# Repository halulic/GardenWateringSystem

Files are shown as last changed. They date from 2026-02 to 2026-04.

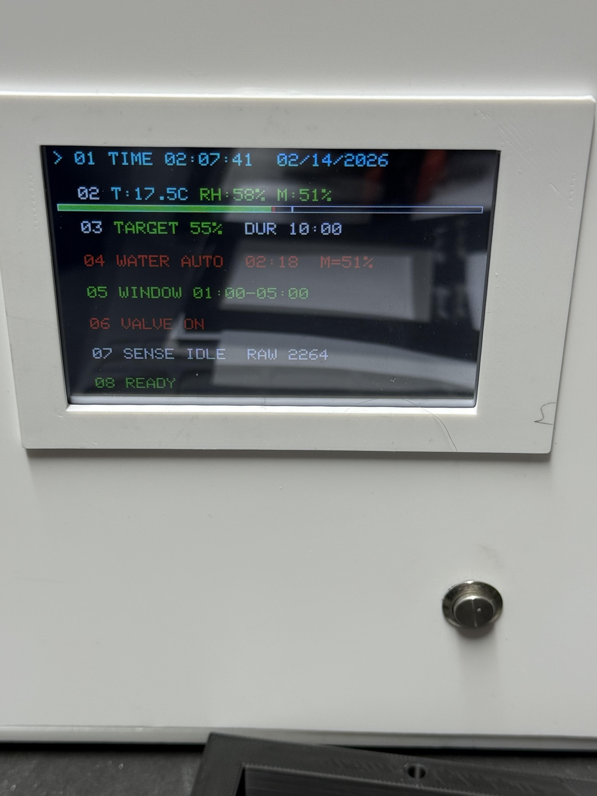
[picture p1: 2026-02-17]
Software/WSscaleALv4CN/GardenWateringSystem/Pictures/fp.jpg

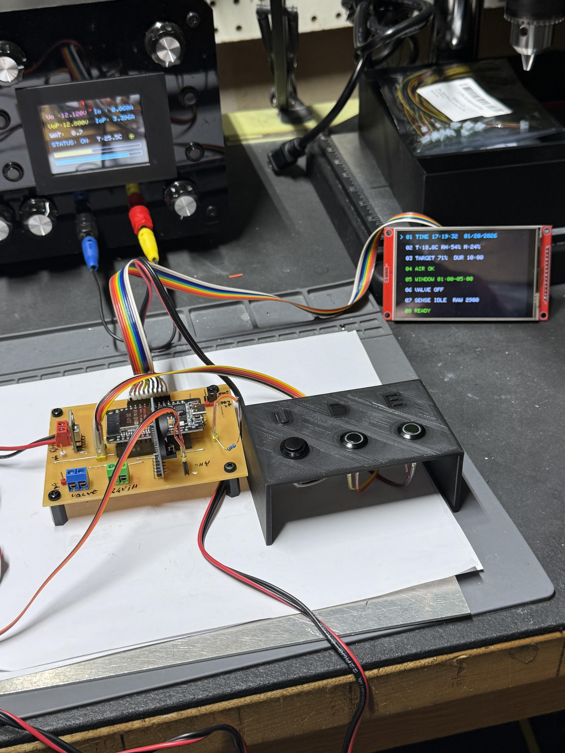
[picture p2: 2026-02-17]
Software/WSscaleALv4CN/GardenWateringSystem/Pictures/ftft.jpg

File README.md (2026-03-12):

Overview

This project is an automatic plant watering system based on ESP32.
It monitors soil moisture, temperature, and humidity and controls a water valve or pump to keep the soil moisture at a defined target level.

The system uses a TFT display for real-time monitoring and allows simple configuration of watering parameters.

⸻

Main Features
	•	Automatic watering based on soil moisture
	•	ESP32 microcontroller
	•	TFT display interface
	•	Real-time monitoring of:
	•	Soil moisture
	•	Temperature
	•	Humidity
	•	Adjustable target moisture level
	•	MOSFET-controlled water valve or pump
	•	Clear visual status indicators on the display

⸻

Hardware

Main components used:
	•	ESP32 development board
	•	Soil moisture sensor
	•	SHT41 temperature & humidity sensor
	•	DS3231 RTC
	•	4.0” TFT display (ILI9488)
	•	MOSFET driver (AO3400)
	•	Water valve or pump
	•	24V power supply (for valves)

⸻

Display Information

The TFT display shows:
	•	Soil moisture percentage
	•	Temperature
	•	Humidity
	•	Target moisture level
	•	Valve status
	•	System status indicators

⸻

Applications
	•	Indoor plant watering
	•	Greenhouse automation
	•	Garden irrigation control
	•	Experimental ESP32 automation projects

⸻

Future Improvements

Planned upgrades include:
	•	WiFi monitoring
	•	Data logging
	•	Mobile notifications
	•	Multi-zone watering control

⸻

License

Open-source project for educational and DIY use.

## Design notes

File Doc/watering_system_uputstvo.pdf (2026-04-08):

## WATERING SYSTEM – UPUTSTVO

Ovaj dokument opisuje rad sistema, navigaciju kroz redove na TFT-u, podešavanja i rad AI (AL) u pozadini.

## ROW 01 – TIME (VREME I DATUM)

Ulaz: kratki ENTER kada je selektovan red 01.
UP/DOWN menjaju vrednosti.
ENTER prelazi na slede■e polje (sat → minut → mesec → dan → godina). Na kraju ENTER potvr■uje i izlazi.

## ROW 02 – MOIST / WET / DRY

Ulaz u edit: držati ENTER 5 sekundi.
Blink ozna■ava aktivno polje.
UP/DOWN menjaju RAW vrednosti (korak 10). ENTER kratko prebacuje izme■u WET i DRY. Držati ENTER ~2 sekunde za save + izlaz. Ove vrednosti su zaklju■ane i AI ih ne menja.

## ROW 03 – TARGET / DUR

Ulaz: kratki ENTER.
TARGET – željena vlažnost (30–85%).
DUR – trajanje zalivanja (3–10 min).
UP/DOWN menjaju vrednosti.
ENTER prelazi izme■u TARGET i DUR, zatim izlaz.

## ROW 04 – SCL (SCALE)

Ulaz: ENTER na red 04.
SCL = skaliranje vlage (60–100%).
UP/DOWN menjaju vrednost po 1%.
ENTER potvr■uje i odmah vrši novo merenje. SCL uti■e i na prikaz i na logiku zalivanja.

## CAL STATUS

CAL+ = kalibracija dobra.
CAL~ = u toku u■enja.
CAL! = problem (sonda ili opseg).

## ROW 07 – SENSE

Prikazuje stanje senzora.
RAW vrednost = direktno o■itanje. OPEN = nema kontakta sa zemljom. SHORT = kratak spoj.

## AI (AL) RAD U POZADINI

AI prati istoriju vlage, temperaturu i ponašanje tla.
Ra■una brzinu sušenja i predvi■a kada ■e pasti ispod TARGET. Detektuje anomalije (skokovi, loš kontakt, bez oporavka).
Ne menja korisni■ke WET/DRY vrednosti.

## KADA O■EKIVATI TA■NE REZULTATE

Osnovna stabilizacija: odmah nakon prvih nekoliko merenja. AI preciznost: nakon 1–3 dana rada.
Optimalno: 3–5 dana kontinuiranog rada.

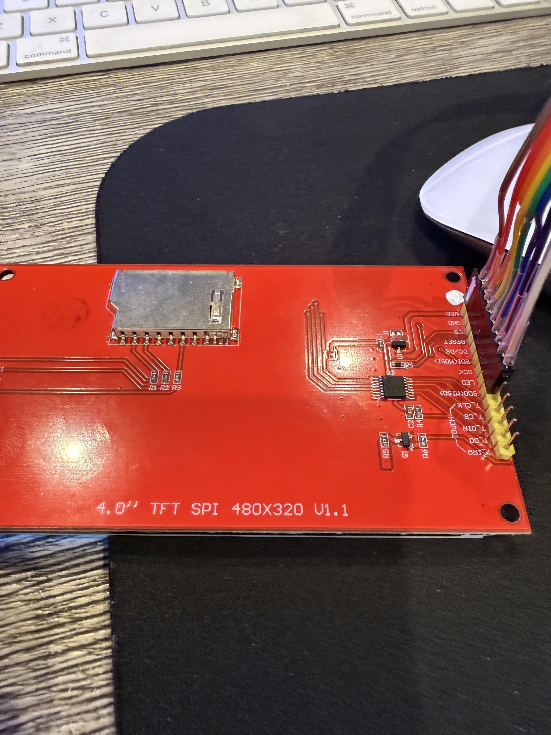
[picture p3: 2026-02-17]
Software/WSscaleALv4CN/GardenWateringSystem/Pictures/tft4in.jpg

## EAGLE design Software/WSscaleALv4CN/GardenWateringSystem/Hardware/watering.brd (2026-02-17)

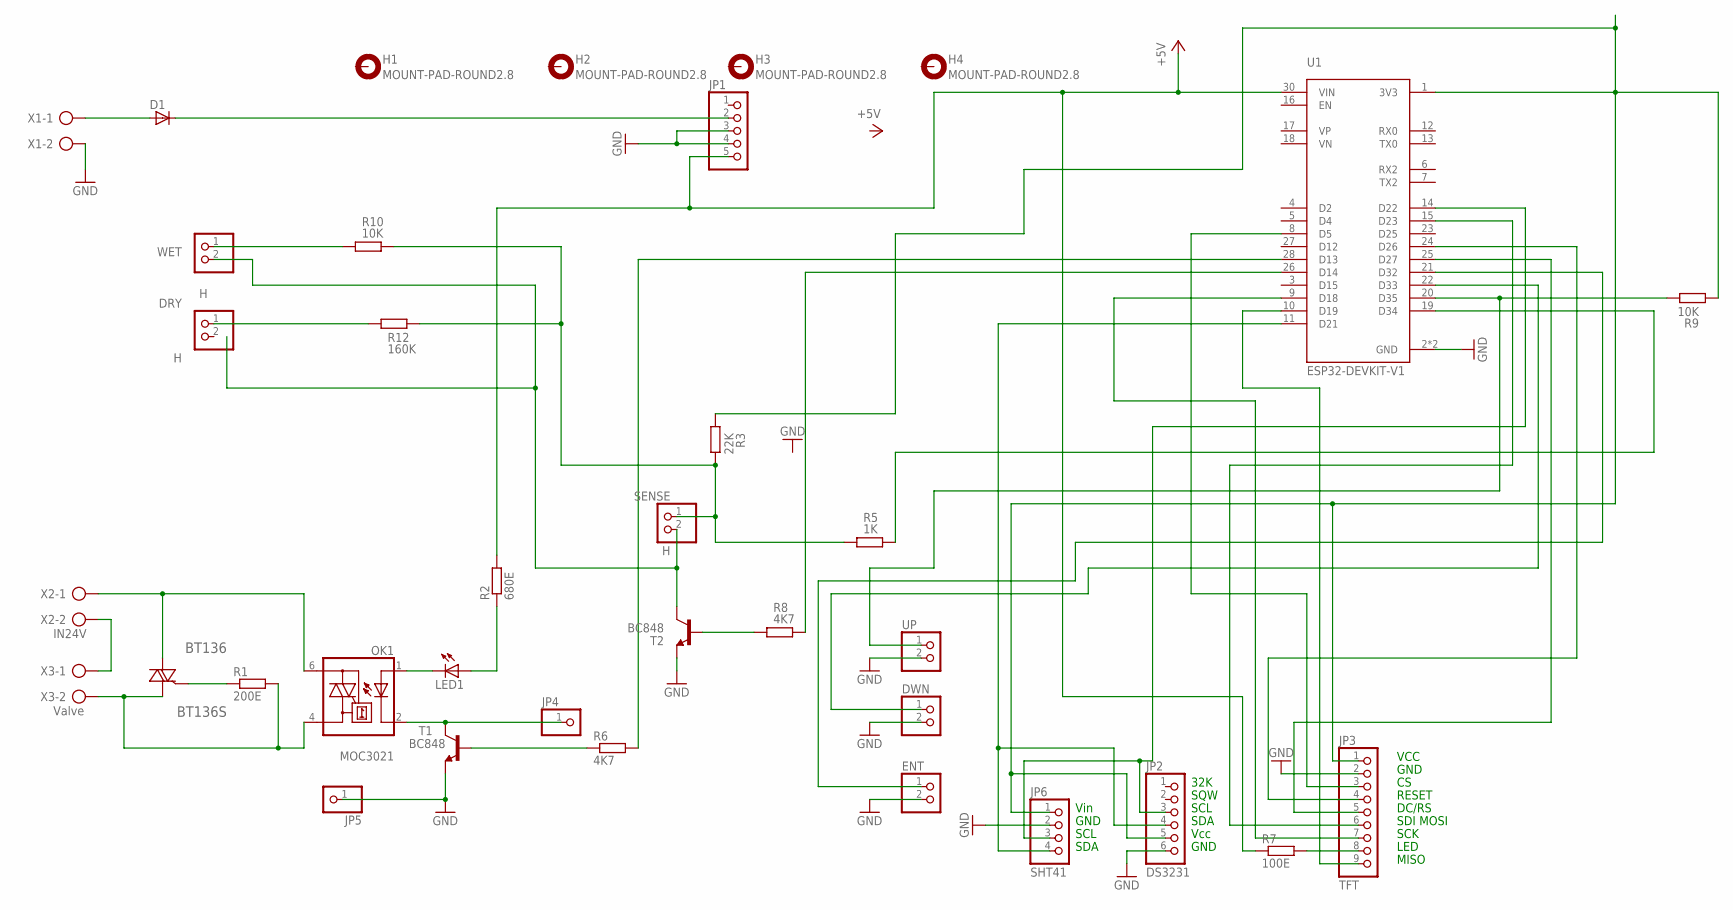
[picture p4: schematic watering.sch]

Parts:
BT136: BT136S; DPAK228P987X240-3N
D1: D-SOD-80; SOD80
DRY: H; 1X02
DWN: PINHD-1X2; 1X02
ENT: PINHD-1X2; 1X02
H1, H2, H3, H4: MOUNT-PAD-ROUND2.8; 2,8-PAD
JP1: PINHD-1X5; 1X05
JP2: DS3231; 1X06
JP3: TFT; 1X09
JP4, JP5: PINHD-1X1; 1X01
JP6: SHT41; 1X04
LED1: LEDCHIPLED_0805; CHIPLED_0805
OK1: MOC3021; DIL6-SMD
R1: 200E; R0603
R2: 680E; R0603
R3: 22K; R0603
R5: 1K; R0603
R6, R8: 4K7; R0603
R7: 100E; R0603
R9, R10: 10K; R0603
R12: 160K; R0603
SENSE: H; 1X02
T1, T2: BC848; SOT23
U1: ESP32-DEVKIT-V1; MODULE_ESP32_DEVKIT_V1
UP: PINHD-1X2; 1X02
WET: H; 1X02
X1: AK300/2
X2: IN24V; AK300/2
X3: Valve; AK300/2

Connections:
+5V: JP1.5, R2.2, R7.1, U1.30 (VIN)
GND: DWN.2, ENT.2, JP1.3, JP1.4, JP2.6, JP3.2, JP5.1, JP6.2, T1.2 (E), T2.2 (E), U1.2 (GND), U1.29 (GND), UP.2, X1.2
unnamed: X2.2, X3.1
unnamed: BT136.1 (A1), OK1.4 (A1), R1.2, X3.2
unnamed: BT136.3 (A2), OK1.6 (A2), X2.1
unnamed: JP2.5, JP3.1, JP6.1, R3.1, R9.1, U1.1 (3V3)
unnamed: BT136.2 (G), R1.1
unnamed: LED1.A, R2.1
unnamed: JP4.1, OK1.2 (C), T1.3 (C)
unnamed: LED1.C, OK1.1 (A)
unnamed: D1.2 (A), X1.1
unnamed: D1.1 (C), JP1.2
unnamed: R3.2, R5.1, R10.2, R12.2, SENSE.1
unnamed: DRY.1, R12.1
unnamed: R6.1, T1.1 (B)
unnamed: JP3.8, R7.2
unnamed: SENSE.2, T2.3 (C), WET.2
unnamed: R8.1, T2.1 (B)
unnamed: R10.1, WET.1
unnamed: JP2.3, JP6.3, U1.14 (D22)
unnamed: JP2.4, JP6.4, U1.11 (D21)
unnamed: JP3.7, U1.9 (D18)
unnamed: R8.2, U1.26 (D14)
unnamed: JP3.6, U1.15 (D23)
unnamed: R9.2, U1.20 (D35), UP.1
unnamed: JP3.3, U1.8 (D5)
unnamed: JP3.5, U1.25 (D27)
unnamed: JP3.4, U1.24 (D26)
unnamed: JP3.9, U1.10 (D19)
unnamed: DWN.1, U1.22 (D33)
unnamed: ENT.1, U1.21 (D32)
unnamed: R6.2, U1.28 (D13)
unnamed: R5.2, U1.19 (D34)

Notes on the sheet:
VCC
GND
RESET
DC/RS
SDI MOSI
SCK
LED
MISO
32K
SQW
SCL
SDA
Vcc
Vin

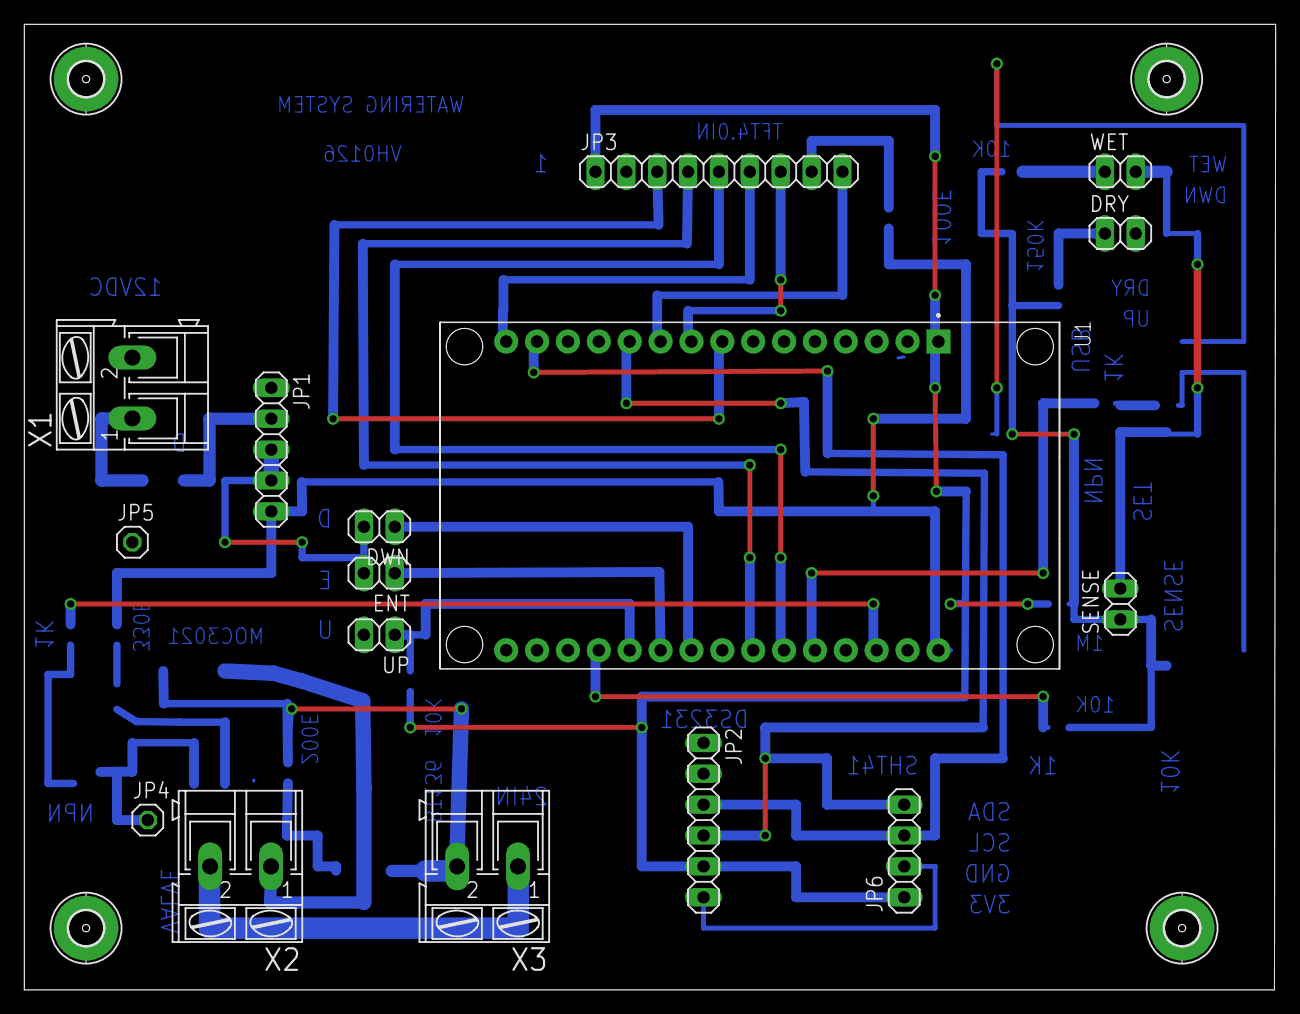
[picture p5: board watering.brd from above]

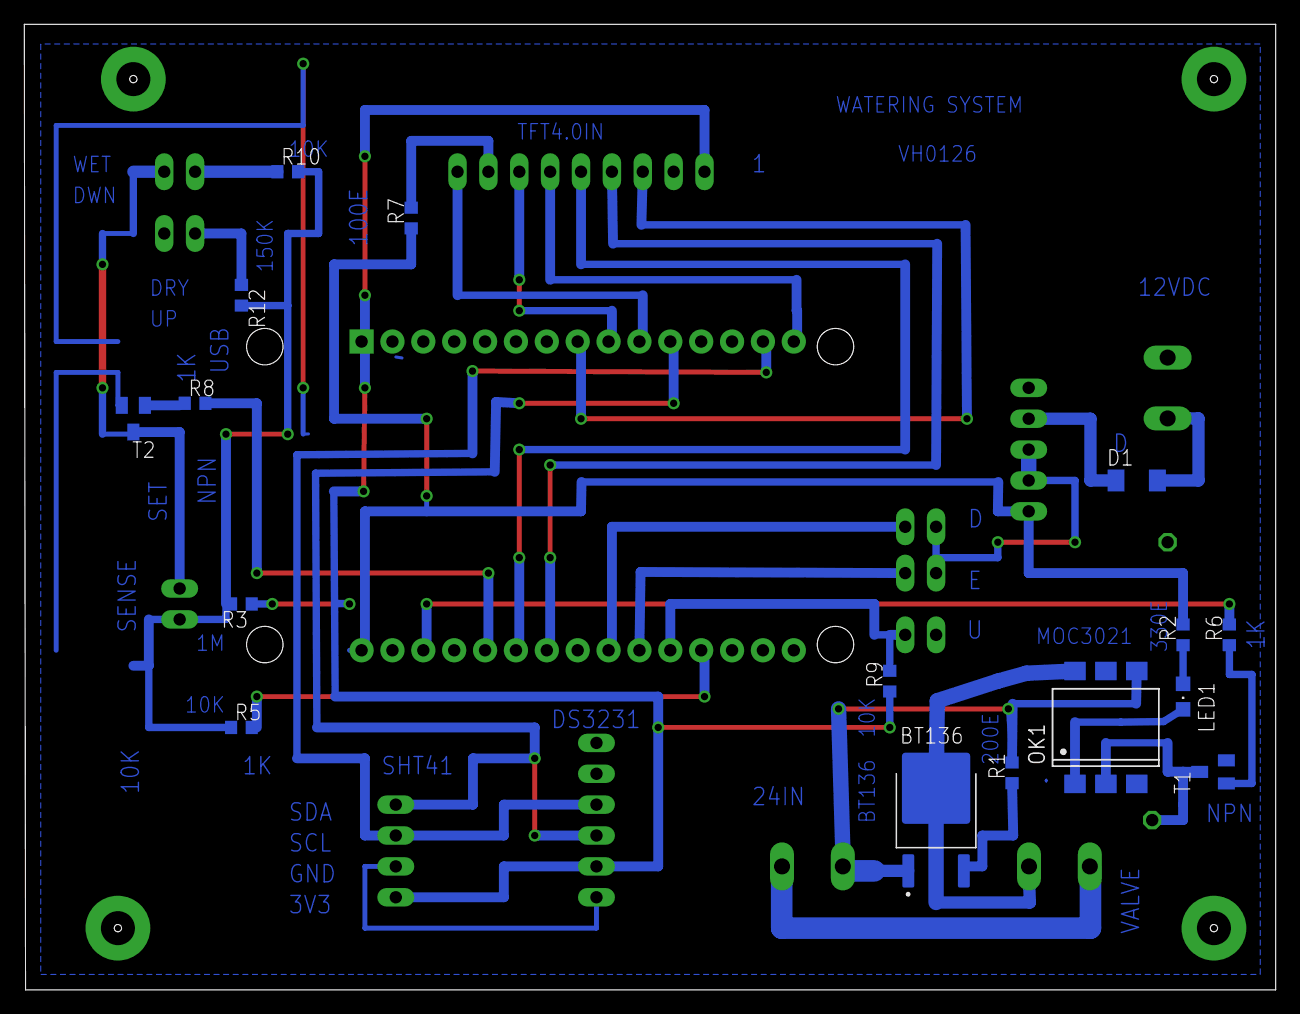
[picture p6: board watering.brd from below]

Board: 2 copper layers, 103.0 x 79.4 mm, 36 parts (16 on the bottom side), 33 nets.

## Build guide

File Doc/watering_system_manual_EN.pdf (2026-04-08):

## WATERING SYSTEM – USER MANUAL

This document explains system operation, TFT rows navigation, settings, and background AI behavior.

## ROW 01 – TIME & DATE

Enter: short ENTER press when row 01 is selected.
UP/DOWN adjust values.
ENTER moves through fields (hour → minute → month → day → year). Final ENTER saves and exits.

## ROW 02 – MOIST / WET / DRY

Enter edit: hold ENTER for 5 seconds.
Blink indicates active field.
UP/DOWN adjust RAW values (step 10).
Short ENTER switches between WET and DRY. Hold ENTER ~2 seconds to save and exit.
These values are user-locked (AI will not modify them).

## ROW 03 – TARGET / DURATION

Enter: short ENTER.
TARGET – desired moisture (30–85%).
DURATION – watering time (3–10 minutes).
UP/DOWN adjust values.
ENTER switches between TARGET and DURATION, then exits.

## ROW 04 – SCALE (SCL)

Enter: ENTER on row 04.
SCL = moisture scaling (60–100%).
UP/DOWN adjust by 1%.
ENTER saves and triggers immediate measurement. Affects both display and watering logic.

## CAL STATUS

CAL+ = calibration OK.
CAL~ = learning in progress.
CAL! = issue detected (sensor or range).

## ROW 07 – SENSOR (SENSE)

Displays sensor status.
RAW value = direct reading.
OPEN = no soil contact.
SHORT = short circuit.

## BACKGROUND AI (AL)

AI monitors moisture history, temperature, and soil behavior.
Calculates drying rate and predicts when moisture drops below TARGET. Detects anomalies (jumps, stuck values, no recovery).
Does NOT modify user WET/DRY settings.

## WHEN TO EXPECT ACCURATE RESULTS

Basic stabilization: after initial measurements.
AI accuracy: after 1–3 days of operation.
Optimal performance: after 3–5 days continuous use.

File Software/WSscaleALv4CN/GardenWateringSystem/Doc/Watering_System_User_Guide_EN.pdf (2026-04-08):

## WATERING SYSTEM – USER GUIDE

This document is a complete user guide for the Watering System. It explains how the system operates, how values are measured and displayed, how parameters are configured, and how the TFT screen information should be interpreted.

VH
01/21/2026 – 03:10 AM (WVC)

### 1. What is the Watering System

The Watering System is an automatic irrigation controller that independently decides when and how long to water based on soil moisture, air temperature, and time.

### Hardware Platform

1 ESP32 Dev Module – 30■pin version (main system controller).
2 4.0" TFT display – graphical presentation of all system information.
3 SHT41 – digital air temperature and humidity sensor.
4 DS3231 – real■time clock (RTC) module for accurate time and date.
5 Soil moisture sensor – resistive type, powered only during measurements. 6 24 VAC irrigation valve – watering control output.

### 2. How the system makes decisions

1 The system operates only within the allowed watering window (01:00–05:00). 2 Air temperature is checked first.
3 If the temperature is ≤ 12 °C, watering is blocked.
4 Soil moisture is then measured.
5 If soil moisture is ≥ TARGET, watering is skipped.
6 If soil moisture is below TARGET, the valve is activated for the set duration (DUR).

### 3. When and how soil moisture is measured

The system does not measure soil moisture continuously. Measurements are performed only at defined moments to ensure reliability and to protect the soil probe from degradation.
1 Before watering (within the 01:00–05:00 window).
2 Immediately after watering has finished.
3 Later during the day at 06:00, 12:00, and 18:00.

### 4. Soil moisture before, during, and after watering

Before watering, the system measures soil moisture and decides whether watering is required. During watering, no new measurement is performed. The last valid moisture value remains displayed while the VALVE status shows ON.
After watering, soil moisture is measured again and the new value is stored as the reference for subsequent decisions.

### 5. Why soil moisture does not increase immediately

After watering, water initially remains near the soil surface. It takes time for moisture to reach the depth where the probe is located. For this reason, an increase in soil moisture is often visible only at the next measurement cycle.

### 6. TFT display – meaning of the information

01 TIME – current time and date.
02 T / RH / M – air temperature, air humidity, and soil moisture. 03 TARGET / DUR – target soil moisture and watering duration. 04 AIR – air status (blocked if too cold).
05 WINDOW – allowed watering time window.
06 VALVE – irrigation valve status.
07 SENSE – measurement status and raw ADC value. 08 READY – system is idle and ready.

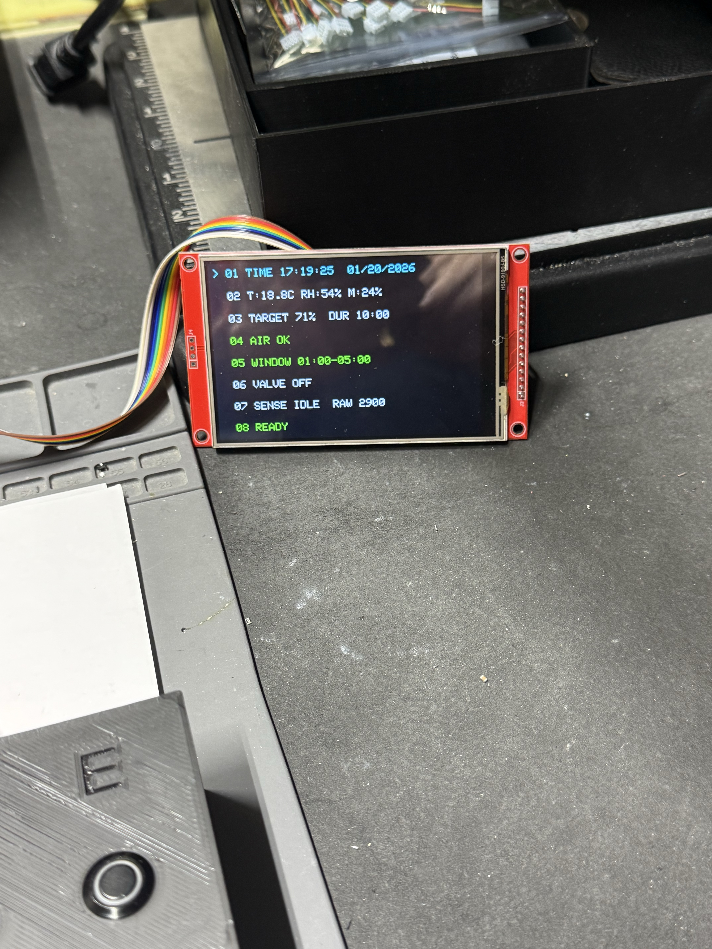
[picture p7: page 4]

### 7. Buttons: UP / DOWN / ENTER

UP – increases the selected value (TARGET or DUR). DOWN – decreases the selected value.
ENTER – confirms a selection or enters a setting mode.
ENTER held during power■up – enters CAL MODE.

### 8. CAL MODE – soil moisture calibration

CAL MODE is used to calibrate the soil moisture sensor. It is entered by holding the ENTER button while powering on the device. CAL MODE is exited by turning the power off and on again.

### 9. WET / DRY calibration

Calibration uses fixed resistors: DRY = 150 kΩ and WET = 10 kΩ. The resistors are connected between SENSE and GND through the NPN transistor collector, exactly as in normal system operation. The calibrated values are stored in memory.

### 10. Typical operating scenarios

1 If the temperature is too low, watering will not occur.
2 If soil moisture is above TARGET, watering is skipped.
3 When READY is displayed, the system is waiting for the next scheduled check.

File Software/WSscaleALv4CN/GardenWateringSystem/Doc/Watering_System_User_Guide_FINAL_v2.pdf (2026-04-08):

## WATERING SYSTEM – USER GUIDE

Ovo je kompletno uputstvo za rad Watering System-a. Sistem je baziran na ESP32 mikrokontroleru (30-pinski modul), koristi 4.0" TFT ekran za prikaz i SHT41 senzor za mjerenje temperature i vlažnosti zraka.

VH
01/21/2026 – 02:53 AM (WVC)

### 1. Hardverska osnova sistema

1 ESP32 Dev Module – 30 pinski modul (glavni kontroler sistema). 2 TFT ekran 4.0" – grafi■ki prikaz svih informacija i statusa sistema.
3 SHT41 – digitalni senzor temperature i vlažnosti zraka.
4 DS3231 – RTC modul za ta■no vrijeme i datum.
5 Senzor vlage tla – otpornog tipa, sa aktivacijom samo tokom mjerenja.
6 24 VAC ventil – upravljanje zalijevanjem.

### 2. Šta je Watering System

Watering System je automatski sistem za zalijevanje koji samostalno odlu■uje kada i koliko zalijevati, na osnovu vlage tla, temperature zraka i vremena.

### 3. Kako sistem razmišlja

1 Sistem radi samo u dozvoljenim vremenskim terminima (01–05).
2 Prvo provjerava temperaturu zraka.
3 Ako je temperatura ≤ 12 °C → zalijevanje je blokirano.
4 Zatim mjeri vlagu tla.
5 Ako je vlaga ≥ TARGET → zalijevanje se preska■e.
6 Ako je vlaga < TARGET → ventil se uklju■uje na DUR minuta.

### 4. Kada i kako sistem mjeri vlagu tla

Sistem ne mjeri vlagu stalno. Mjerenje se vrši samo u ta■no odre■enim trenucima radi pouzdanosti i zaštite sonde.
1 Prije zalijevanja (01–05).
2 Odmah nakon završenog zalijevanja.
3 Kasnije tokom dana u 06:00, 12:00 i 18:00.

### 5. Vlažnost tla prije, tokom i nakon zalijevanja

Prije zalijevanja sistem mjeri vlagu tla i donosi odluku da li je zalijevanje potrebno.
Tokom zalijevanja ne vrši se novo mjerenje. Na ekranu ostaje posljednja izmjerena vrijednost, dok red VALVE pokazuje stanje ON.
Nakon zalijevanja sistem ponovo mjeri vlagu tla i ta vrijednost se koristi kao nova referenca.

### 6. Zašto se vlaga ne pove■a odmah nakon zalijevanja

Voda nakon zalijevanja ostaje u gornjem sloju tla i potrebno je vrijeme da dopre do dubine na kojoj se nalazi sonda. Zbog toga se porast vlage ■esto vidi tek na sljede■em mjerenju.

### 7. TFT ekran – zna■enje prikaza

01 TIME – trenutno vrijeme i datum.
02 T / RH / M – temperatura zraka, vlažnost zraka i vlaga tla. 03 TARGET / DUR – ciljana vlaga i trajanje zalijevanja.
04 AIR – status zraka (blokada ako je hladno).
05 WINDOW – dozvoljeni vremenski prozor.
06 VALVE – stanje ventila.
07 SENSE – stanje mjerenja i RAW vrijednost. 08 READY – sistem spreman za rad.


### 8. Tasteri UP / DOWN / ENTER

UP – pove■ava vrijednost (TARGET, DUR). DOWN – smanjuje vrijednost.
ENTER – potvrda ili ulaz u podešavanje.
ENTER držan pri paljenju – ulazak u CAL MODE.

### 9. CAL MODE – kalibracija vlage

CAL MODE služi za kalibraciju senzora vlage tla. Ulazi se držanjem ENTER tastera tokom uklju■enja ure■aja. Izlazak iz CAL MODE je isklju■ivanje i ponovno uklju■ivanje napajanja.

### 10. WET / DRY kalibracija

Za kalibraciju se koriste otpornici: DRY = 150 kΩ i WET = 10 kΩ. Otpornici se spajaju izme■u SENSE i GND preko kolektora NPN tranzistora, isto kao u normalnom radu sistema. Vrijednosti se pamte u memoriji.

### 11. Tipi■ni scenariji

1 Ako je hladno → sistem ne■e zalijevati.
2 Ako je vlaga iznad TARGET → zalijevanje se preska■e. 3 Ako piše READY → sistem ■eka sljede■i termin.

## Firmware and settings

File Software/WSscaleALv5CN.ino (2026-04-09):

#include <Wire.h>
#include <RTClib.h>
#include <Adafruit_SHT4x.h>
#include <Arduino_GFX_Library.h>
#include <Preferences.h>
#include <math.h>

#define TFT_CS   5
#define TFT_DC   27
#define TFT_RST  26
#define TFT_SCK  18
#define TFT_MOSI 23
#define TFT_MISO -1

#define I2C_SDA  21
#define I2C_SCL  22

#define PIN_UP      35
#define PIN_DOWN    33
#define PIN_ENTER   32

#define PIN_SENSE_EN   14
#define PIN_SENSE_ADC  34
#define PIN_VALVE      13

Arduino_DataBus *bus = new Arduino_HWSPI(TFT_DC, TFT_CS, TFT_SCK, TFT_MOSI, TFT_MISO);
Arduino_GFX *gfx = new Arduino_ILI9488_18bit(bus, TFT_RST, 1, false);

uint16_t C_BLACK, C_WHITE, C_GREEN, C_YELLOW, C_RED, C_CYAN;
uint16_t C_SPRING, C_SUMMER, C_AMBER;

RTC_DS3231 rtc;
Adafruit_SHT4x sht4;
Preferences prefs;

static const int ROWS = 8;
static const int ROW_H = 40;
static const int LEFT = 8;

int TARGET = 50;
int DUR_MIN = 5;
int SCALE_PCT = 75;

static const int WINDOW_START_H = 1;
static const int WINDOW_END_H   = 5;

static const int DAILY_READ_H1 = 6;
static const int DAILY_READ_H2 = 12;
static const int DAILY_READ_H3 = 18;

static const int CAL_STEP = 10;
static const int SCALE_MIN = 60;
static const int SCALE_MAX = 100;
static const int TARGET_MIN = 30;
static const int TARGET_MAX = 85;

static const uint32_t CAL_ENTER_HOLD_MS = 5000;
static const uint32_t CAL_SAVE_EXIT_MS  = 2000;
static const uint32_t BLINK_MS = 350;

#define SOIL_RAW_SHORT_MAX   60
#define SOIL_RAW_OPEN_MIN    3850

static const int RAW_WET_INIT = 700;
static const int RAW_DRY_INIT = 2800;

int RAW_DRY = RAW_DRY_INIT;
int RAW_WET = RAW_WET_INIT;

int calDry = RAW_DRY_INIT;
int calWet = RAW_WET_INIT;

enum CalBgState {
  CAL_BG_LEARN = 0,
  CAL_BG_OK    = 1,
  CAL_BG_WARN  = 2
};

uint8_t calBgState = CAL_BG_OK;

float airT = NAN;
float airRH = NAN;

int moistRaw = 0;
int moistPct = 0;
int moistPctBaseFiltered = 0;

bool senseIdle = true;
bool tempBlock = false;

bool watering = false;
bool wateringManual = false;
uint32_t wateringEndMs = 0;

String lastLine[ROWS];
uint16_t lastFg[ROWS];

uint32_t lastAutoKey = 0;
uint32_t lastDailyKey = 0;

bool calEnterHoldFired = false;
bool calSaveHoldFired = false;
bool calBlinkOn = true;
uint32_t calBlinkMs = 0;
bool calWaitReleaseAfterEnter = false;

int  lastBarPct = -1;
int  lastBarTgt = -1;
bool lastBarHl  = false;

static const int SOIL_READ_SAMPLES = 24;
static const int SOIL_READ_DELAY_MS = 2;
static const int SOIL_RAW_DEADBAND = 18;
static const int SOIL_RAW_SNAP_BAND = 10;

static const float SOIL_TEMP_REF_C = 20.0f;
static const float SOIL_TEMP_RAW_PER_C = 6.0f;

static const int AI_HISTORY_MAX = 32;

static const int AI_JUMP_RAW_THRESHOLD = 450;
static const int AI_STUCK_RAW_WINDOW = 12;
static const int AI_STUCK_RAW_DELTA = 4;
static const int AI_RECOVERY_MIN_DELTA = 40;
static const uint32_t AI_RECOVERY_WINDOW_MS = 45UL * 60UL * 1000UL;

static const uint16_t SOIL_STARTUP_SETTLE_MS = 220;
static const uint16_t SOIL_NORMAL_SETTLE_MS  = 150;
static const uint8_t  SOIL_STARTUP_INTERNAL_READS = 3;
static const uint8_t  SOIL_NORMAL_INTERNAL_READS  = 3;
static const int      SOIL_STARTUP_STABLE_BAND = 35;
static const int      SOIL_NORMAL_STABLE_BAND  = 30;
static const uint8_t  SOIL_MAX_RETRIES = 2;

struct AiPoint {
  uint32_t epoch;
  int raw;
  int rawTempComp;
  int pct;
  float tC;
  float rh;
  bool wateringState;
  bool valid;
};

AiPoint aiHist[AI_HISTORY_MAX];
int aiHistCount = 0;
int aiHistHead = 0;

int moistRawFiltered = 0;
int moistPctFiltered = 0;
bool moistFilterPrimed = false;

float aiDryRatePctPerHour = 0.0f;
float aiPredHoursToTarget = -1.0f;
float aiConfidence = 0.0f;

bool aiAnomalyJump = false;
bool aiAnomalyStuck = false;
bool aiAnomalyNoRecovery = false;
bool aiSensorHealthBad = false;

bool aiSoilVeryWet = false;
bool aiSoilWet = false;
bool aiSoilOk = false;
bool aiSoilDry = false;
bool aiSoilCritical = false;

bool aiPrevWatering = false;
uint32_t aiLastWaterStopMs = 0;
int aiRawAtWaterStop = 0;

struct Button {
  int pin;
  bool activeLow = true;
  bool stable = false;
  bool raw = false;
  uint32_t lastChangeMs = 0;
  bool shortPress = false;
  bool longPress = false;
  bool longFired = false;
  uint32_t pressStartMs = 0;
  uint16_t debounceMs = 25;
  uint16_t longMs = 650;

  void begin(int p){
    pin = p;
    if(pin >= 34) pinMode(pin, INPUT);
    else pinMode(pin, INPUT_PULLUP);
    bool r = readRawPressed();
    stable = r;
    raw = r;
    lastChangeMs = millis();
  }

  bool readRawPressed(){
    int v = digitalRead(pin);
    return activeLow ? (v == LOW) : (v == HIGH);
  }

  void update(){
    shortPress = false;
    longPress = false;

    bool r = readRawPressed();
    uint32_t now = millis();

    if(r != raw){
      raw = r;
      lastChangeMs = now;
    }

    if((now - lastChangeMs) >= debounceMs){
      if(stable != raw){
        stable = raw;
        if(stable){
          pressStartMs = now;
          longFired = false;
        } else {
          if(!longFired) shortPress = true;
        }
      }
    }

    if(stable && !longFired && (now - pressStartMs) >= longMs){
      longFired = true;
      longPress = true;
    }
  }
};

Button btnUp, btnDown, btnEnter;

enum UiMode {
  UI_NAV,
  UI_EDIT_TIME_H, UI_EDIT_TIME_M, UI_EDIT_DATE_MO, UI_EDIT_DATE_D, UI_EDIT_DATE_Y,
  UI_EDIT_TARGET, UI_EDIT_DUR,
  UI_EDIT_WET_DRY,
  UI_EDIT_ROW4_SCALE
};

UiMode uiMode = UI_NAV;

int selRow = 0;
const int SEL_MIN = 0;
const int SEL_MAX = 4;

enum CalFieldSel {
  CAL_FIELD_WET = 0,
  CAL_FIELD_DRY = 1
};

CalFieldSel calEditField = CAL_FIELD_WET;
int eDry = RAW_DRY_INIT;
int eWet = RAW_WET_INIT;
int eScale = 75;

int eHour=0, eMin=0, eDay=1, eMonth=1, eYear=2026;

int clampi(int x, int lo, int hi);
float clampf(float x, float lo, float hi);
String two(int v);

bool soilIsShort(int raw);
bool soilIsOpen(int raw);

uint32_t makeAutoKey(const DateTime &t);
uint32_t rtcNowEpoch();

int mapMoistPctCal(int raw);
int applyScaleToPct(int pct);
int applySoilTempCompToRaw(int raw, float tC);
int applyDeadbandToRaw(int newRaw, int oldRaw);
int filterSoilRawSimple(int newRaw);

void aiResetStates();
AiPoint aiGetHist(int idxFromOldest);
void aiPushPoint(uint32_t epoch, int raw, int rawTempComp, int pct, float tC, float rh, bool wateringState);
void aiUpdateSoilStateFromPct(int pct);
int aiCountRecentStableRaw();
void aiEvaluateJumpAnomaly();
void aiEvaluateStuckAnomaly();
void aiEvaluateRecoveryAnomaly(uint32_t nowMs, int currentRawTempComp);
void aiEvaluateSensorHealth();
void aiComputeDryRateAndPrediction();
void aiUpdateAll(uint32_t nowMs);
void aiHandleWateringEdge(uint32_t nowMs);

void calSyncDisplayedValues();
void calUpdateState();
void calSaveNow();
String calStateText();

void drawRowTextOnBlack(int r, const String &s, uint16_t fg);
String withSelPrefix(const String &s, bool sel);

int readSoilAveragedCore(uint16_t settleMs);
int readSoilValidated(bool startupMode, bool keepSenseOn);
int readSoilOncePulsed(bool startupMode = false);
int readSoilOnceCalFast(bool startupMode = false);

void processSoilMeasurement(int rawMeasured, bool pushToHistory);
void startWatering(bool manual, int minutes);
void stopWatering();

bool isLeap(int y);
int daysInMonth(int y, int m);
void normalizeDate();
void loadEditFromRTC();
void saveEditToRTC();

bool rowIsHighlighted(int r);
uint16_t seasonTimeColorByMonth(int month);
uint16_t colorSoilPctBands(int pct);
uint16_t colorTempBands(float tC);
uint16_t colorRH(float rh);

void drawMoistBar_NoFlicker(bool hl);
void drawRow2Colored_NoFlicker(bool hl);
void drawRow3Colored_NoFlicker(bool hl);

String buildTimeRow(const DateTime &now);
String buildRow2();
String buildRow3();
String buildRow4Idle();
String buildRow5();

void loadSettings();
void saveSettings();
void remeasureSoilNow(bool pushToHistory);

bool isDailyReadTime(const DateTime &t);
bool isWetDryEditMode();

int median3(int a, int b, int c);

int clampi(int x, int lo, int hi){
  if(x < lo) return lo;
  if(x > hi) return hi;
  return x;
}

float clampf(float x, float lo, float hi){
  if(x < lo) return lo;
  if(x > hi) return hi;
  return x;
}

String two(int v){
  char b[8];
  snprintf(b, sizeof(b), "%02d", v);
  return String(b);
}

bool soilIsShort(int raw){ return (raw <= SOIL_RAW_SHORT_MAX); }
bool soilIsOpen (int raw){ return (raw >= SOIL_RAW_OPEN_MIN); }

uint32_t makeAutoKey(const DateTime &t){
  return (uint32_t)t.year() * 1000000UL +
         (uint32_t)t.month() * 10000UL +
         (uint32_t)t.day() * 100UL +
         (uint32_t)t.hour();
}

uint32_t rtcNowEpoch(){
  DateTime n = rtc.now();
  return n.unixtime();
}

int median3(int a, int b, int c){
  if(a > b){ int t = a; a = b; b = t; }
  if(b > c){ int t = b; b = c; c = t; }
  if(a > b){ int t = a; a = b; b = t; }
  return b;
}

int mapMoistPctCal(int raw){
  raw = clampi(raw, 0, 4095);

  if(soilIsShort(raw)) return 100;
  if(soilIsOpen(raw))  return 0;

  int dry = calDry;
  int wet = calWet;

  if(wet >= dry){
    int t = wet; wet = dry; dry = t;
  }

  if(raw >= dry) return 0;
  if(raw <= wet) return 100;

  long num = (long)(dry - raw) * 100L;
  long den = (long)(dry - wet);
  if(den <= 0) return 0;

  int pct = (int)(num / den);
  return clampi(pct, 0, 100);
}

int applyScaleToPct(int pct){
  pct = clampi(pct, 0, 100);
  long scaled = ((long)pct * (long)SCALE_PCT + 50L) / 100L;
  return clampi((int)scaled, 0, 100);
}

int applySoilTempCompToRaw(int raw, float tC){
  if(!isfinite(tC)) return raw;
  if(soilIsOpen(raw) || soilIsShort(raw)) return raw;

  float deltaC = (SOIL_TEMP_REF_C - tC);
  float corr = deltaC * SOIL_TEMP_RAW_PER_C;

  int corrected = (int)lroundf((float)raw + corr);
  return clampi(corrected, 0, 4095);
}

int applyDeadbandToRaw(int newRaw, int oldRaw){
  if(!moistFilterPrimed) return newRaw;

  int diff = newRaw - oldRaw;
  if(abs(diff) <= SOIL_RAW_SNAP_BAND) return oldRaw;
  if(abs(diff) <= SOIL_RAW_DEADBAND)  return oldRaw;

  return newRaw;
}

int filterSoilRawSimple(int newRaw){
  if(!moistFilterPrimed){
    moistFilterPrimed = true;
    moistRawFiltered = newRaw;
    return moistRawFiltered;
  }

  newRaw = applyDeadbandToRaw(newRaw, moistRawFiltered);

  float filtered = 0.70f * (float)moistRawFiltered + 0.30f * (float)newRaw;
  moistRawFiltered = (int)lroundf(filtered);

  return moistRawFiltered;
}

void calSyncDisplayedValues(){
  RAW_DRY = calDry;
  RAW_WET = calWet;
}

void calUpdateState(){
  if(soilIsOpen(moistRaw) || soilIsShort(moistRaw) || aiSensorHealthBad){
    calBgState = CAL_BG_WARN;
    return;
  }

  if((calDry - calWet) < 250){
    calBgState = CAL_BG_WARN;
    return;
  }

  calBgState = CAL_BG_OK;
}

void calSaveNow(){
  saveSettings();
  calUpdateState();
}

String calStateText(){
  if(calBgState == CAL_BG_WARN) return "CAL!";
  if(calBgState == CAL_BG_OK)   return "CAL+";
  return "CAL~";
}

void aiResetStates(){
  aiDryRatePctPerHour = 0.0f;
  aiPredHoursToTarget = -1.0f;
  aiConfidence = 0.0f;

  aiAnomalyJump = false;
  aiAnomalyStuck = false;
  aiAnomalyNoRecovery = false;
  aiSensorHealthBad = false;

  aiSoilVeryWet = false;
  aiSoilWet = false;
  aiSoilOk = false;
  aiSoilDry = false;
  aiSoilCritical = false;
}

AiPoint aiGetHist(int idxFromOldest){
  AiPoint emptyPoint;
  emptyPoint.epoch = 0;
  emptyPoint.raw = 0;
  emptyPoint.rawTempComp = 0;
  emptyPoint.pct = 0;
  emptyPoint.tC = NAN;
  emptyPoint.rh = NAN;
  emptyPoint.wateringState = false;
  emptyPoint.valid = false;

  if(idxFromOldest < 0 || idxFromOldest >= aiHistCount) return emptyPoint;

  int first = (aiHistHead - aiHistCount + AI_HISTORY_MAX) % AI_HISTORY_MAX;
  int idx = (first + idxFromOldest) % AI_HISTORY_MAX;
  return aiHist[idx];
}

void aiPushPoint(uint32_t epoch, int raw, int rawTempComp, int pct, float tC, float rh, bool wateringState){
  AiPoint p;
  p.epoch = epoch;
  p.raw = raw;
  p.rawTempComp = rawTempComp;
  p.pct = pct;
  p.tC = tC;
  p.rh = rh;
  p.wateringState = wateringState;
  p.valid = true;

  aiHist[aiHistHead] = p;
  aiHistHead = (aiHistHead + 1) % AI_HISTORY_MAX;
  if(aiHistCount < AI_HISTORY_MAX) aiHistCount++;
}

void aiUpdateSoilStateFromPct(int pct){
  aiSoilVeryWet  = (pct >= 85);
  aiSoilWet      = (pct >= 66 && pct < 85);
  aiSoilOk       = (pct >= 41 && pct < 66);
  aiSoilDry      = (pct >= 21 && pct < 41);
  aiSoilCritical = (pct <= 20);
}

int aiCountRecentStableRaw(){
  if(aiHistCount < 2) return 0;

  int count = 1;
  AiPoint prev = aiGetHist(aiHistCount - 1);

  for(int i = aiHistCount - 2; i >= 0; i--){
    AiPoint p = aiGetHist(i);
    if(!p.valid || !prev.valid) break;

    if(abs(prev.rawTempComp - p.rawTempComp) <= AI_STUCK_RAW_DELTA){
      count++;
      prev = p;
    } else {
      break;
    }
  }

  return count;
}

void aiEvaluateJumpAnomaly(){
  aiAnomalyJump = false;
  if(aiHistCount < 2) return;

  AiPoint a = aiGetHist(aiHistCount - 2);
  AiPoint b = aiGetHist(aiHistCount - 1);
  if(!a.valid || !b.valid) return;

  if(abs(b.rawTempComp - a.rawTempComp) >= AI_JUMP_RAW_THRESHOLD){
    aiAnomalyJump = true;
  }
}

void aiEvaluateStuckAnomaly(){
  aiAnomalyStuck = false;
  int stableCnt = aiCountRecentStableRaw();
  if(stableCnt >= AI_STUCK_RAW_WINDOW){
    aiAnomalyStuck = true;
  }
}
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
void loop(){
  btnUp.update();
  btnDown.update();
  btnEnter.update();

  DateTime now = rtc.now();

  aiHandleWateringEdge(millis());

  if(uiMode == UI_EDIT_WET_DRY){
    if(millis() - calBlinkMs >= BLINK_MS){
      calBlinkMs = millis();
      calBlinkOn = !calBlinkOn;
      lastLine[1] = "";
    }
  } else {
    calBlinkOn = true;
  }

  if(!btnEnter.stable){
    calEnterHoldFired = false;
    calSaveHoldFired = false;

    if(calWaitReleaseAfterEnter){
      calWaitReleaseAfterEnter = false;
    }
  }

  static uint32_t lastSHTms = 0;
  if(millis() - lastSHTms >= 1000){
    lastSHTms = millis();

    sensors_event_t hum, temp;
    if(sht4.getEvent(&hum, &temp)){
      airT = temp.temperature;
      airRH = hum.relative_humidity;
    }

    bool newTempBlock = (isfinite(airT) && airT <= 12.0f);
    if(newTempBlock != tempBlock){
      tempBlock = newTempBlock;
      lastLine[2] = "";
      lastLine[5] = "";
    }

    lastLine[1] = "";
  }

  if(uiMode != UI_EDIT_WET_DRY){
    digitalWrite(PIN_SENSE_EN, LOW);
    senseIdle = true;

    if(isDailyReadTime(now)){
      uint32_t key = makeAutoKey(now);
      if(key != lastDailyKey){
        lastDailyKey = key;

        int raw = readSoilOncePulsed(false);
        processSoilMeasurement(raw, true);
      }
    }
  }

  if(uiMode == UI_NAV){

    if(btnUp.shortPress){
      selRow = clampi(selRow - 1, SEL_MIN, SEL_MAX);
      lastLine[0] = "";
      lastLine[1] = "";
      lastLine[2] = "";
      lastLine[3] = "";
      lastLine[4] = "";
    }

    if(btnDown.shortPress){
      selRow = clampi(selRow + 1, SEL_MIN, SEL_MAX);
      lastLine[0] = "";
      lastLine[1] = "";
      lastLine[2] = "";
      lastLine[3] = "";
      lastLine[4] = "";
    }

    if(btnEnter.shortPress){
      if(selRow == 0){
        loadEditFromRTC();
        uiMode = UI_EDIT_TIME_H;
        lastLine[0] = "";
      }
      else if(selRow == 2){
        uiMode = UI_EDIT_TARGET;
        lastLine[2] = "";
      }
      else if(selRow == 3){
        eScale = SCALE_PCT;
        uiMode = UI_EDIT_ROW4_SCALE;
        lastLine[3] = "";
      }
    }

    if(selRow == 1 && btnEnter.stable && !calEnterHoldFired){
      if((millis() - btnEnter.pressStartMs) >= CAL_ENTER_HOLD_MS){
        calEnterHoldFired = true;

        uiMode = UI_EDIT_WET_DRY;
        calEditField = CAL_FIELD_WET;
        eWet = calWet;
        eDry = calDry;
        calBlinkOn = true;
        calBlinkMs = millis();

        calWaitReleaseAfterEnter = true;
        calSaveHoldFired = false;

        digitalWrite(PIN_SENSE_EN, LOW);
        senseIdle = true;

        lastLine[1] = "";
        lastLine[2] = "";
        lastLine[6] = "";
      }
    }

    if(btnEnter.longPress && selRow != 1 && selRow != 2 && selRow != 3){
      if(watering) stopWatering();
      else startWatering(true, DUR_MIN);

      lastLine[3] = "";
      lastLine[5] = "";
    }
  }

  else if(uiMode == UI_EDIT_WET_DRY){

    if(!calWaitReleaseAfterEnter){

      if(btnUp.shortPress){
        if(calEditField == CAL_FIELD_WET){
          eWet = clampi(eWet + CAL_STEP, 0, eDry - 250);
        } else {
          eDry = clampi(eDry + CAL_STEP, eWet + 250, 4095);
        }
        lastLine[1] = "";
      }

      if(btnDown.shortPress){
        if(calEditField == CAL_FIELD_WET){
          eWet = clampi(eWet - CAL_STEP, 0, eDry - 250);
        } else {
          eDry = clampi(eDry - CAL_STEP, eWet + 250, 4095);
        }
        lastLine[1] = "";
      }

      if(btnEnter.shortPress){
        calEditField = (calEditField == CAL_FIELD_WET) ? CAL_FIELD_DRY : CAL_FIELD_WET;
        calBlinkOn = true;
        calBlinkMs = millis();
        lastLine[1] = "";
      }

      if(btnEnter.stable && !calSaveHoldFired){
        uint32_t held = millis() - btnEnter.pressStartMs;

        if(held >= CAL_SAVE_EXIT_MS){
          calSaveHoldFired = true;

          calWet = clampi(eWet, 0, 4095);
          calDry = clampi(eDry, 0, 4095);

          if((calDry - calWet) < 250){
            calDry = clampi(calWet + 250, 0, 4095);
          }

          calSyncDisplayedValues();
          calSaveNow();

          uiMode = UI_NAV;
          digitalWrite(PIN_SENSE_EN, LOW);
          senseIdle = true;

          remeasureSoilNow(true);

          lastLine[0] = "";
          lastLine[1] = "";
          lastLine[2] = "";
          lastLine[3] = "";
          lastLine[4] = "";
          lastLine[6] = "";
        }
      }
    }
  }

  else if(uiMode == UI_EDIT_TARGET){

    if(btnUp.shortPress){
      TARGET = clampi(TARGET + 1, TARGET_MIN, TARGET_MAX);
      saveSettings();
      lastLine[2] = "";
    }

    if(btnDown.shortPress){
      TARGET = clampi(TARGET - 1, TARGET_MIN, TARGET_MAX);
      saveSettings();
      lastLine[2] = "";
    }

    lastBarTgt = -1;

    if(btnEnter.shortPress){
      uiMode = UI_EDIT_DUR;
      lastLine[2] = "";
    }
  }

  else if(uiMode == UI_EDIT_DUR){

    if(btnUp.shortPress){
      DUR_MIN = clampi(DUR_MIN + 1, 3, 10);
      saveSettings();
      lastLine[2] = "";
    }

    if(btnDown.shortPress){
      DUR_MIN = clampi(DUR_MIN - 1, 3, 10);
      saveSettings();
      lastLine[2] = "";
    }

    if(btnEnter.shortPress){
      uiMode = UI_NAV;
      lastLine[0] = "";
      lastLine[1] = "";
      lastLine[2] = "";
      lastLine[3] = "";
      lastLine[4] = "";
    }
  }

  else if(uiMode == UI_EDIT_ROW4_SCALE){

    if(btnUp.shortPress){
      eScale = clampi(eScale + 1, SCALE_MIN, SCALE_MAX);
      lastLine[3] = "";
    }

    if(btnDown.shortPress){
      eScale = clampi(eScale - 1, SCALE_MIN, SCALE_MAX);
      lastLine[3] = "";
    }

    if(btnEnter.shortPress){
      SCALE_PCT = clampi(eScale, SCALE_MIN, SCALE_MAX);
      saveSettings();
      remeasureSoilNow(true);

      uiMode = UI_NAV;
      lastLine[1] = "";
      lastLine[2] = "";
      lastLine[3] = "";
      lastLine[4] = "";
      lastLine[6] = "";
    }

    if(btnEnter.longPress){
      uiMode = UI_NAV;
      lastLine[3] = "";
      lastLine[4] = "";
    }
  }

  else {
    if(btnEnter.longPress){
      uiMode = UI_NAV;
      lastLine[0] = "";
      lastLine[1] = "";
      lastLine[2] = "";
      lastLine[3] = "";
      lastLine[4] = "";
    } else {
      if(btnUp.shortPress || btnDown.shortPress){
        int dir = btnUp.shortPress ? +1 : -1;

        if(uiMode == UI_EDIT_TIME_H) eHour = (eHour + dir + 24) % 24;
        else if(uiMode == UI_EDIT_TIME_M) eMin = (eMin + dir + 60) % 60;
        else if(uiMode == UI_EDIT_DATE_MO){
          eMonth = clampi(eMonth + dir, 1, 12);
          normalizeDate();
        }
        else if(uiMode == UI_EDIT_DATE_D){
          int dim = daysInMonth(eYear, eMonth);
          eDay = clampi(eDay + dir, 1, dim);
        }
        else if(uiMode == UI_EDIT_DATE_Y){
          eYear = clampi(eYear + dir, 2020, 2099);
          normalizeDate();
        }

        lastLine[0] = "";
      }

      if(btnEnter.shortPress){
        if(uiMode == UI_EDIT_TIME_H) uiMode = UI_EDIT_TIME_M;
        else if(uiMode == UI_EDIT_TIME_M) uiMode = UI_EDIT_DATE_MO;
        else if(uiMode == UI_EDIT_DATE_MO) uiMode = UI_EDIT_DATE_D;
        else if(uiMode == UI_EDIT_DATE_D)  uiMode = UI_EDIT_DATE_Y;
        else if(uiMode == UI_EDIT_DATE_Y){
          saveEditToRTC();
          uiMode = UI_NAV;
          lastLine[0] = "";
          lastLine[1] = "";
          lastLine[2] = "";
          lastLine[3] = "";
          lastLine[4] = "";
        }
      }
    }
  }

  if(watering){
    if((int32_t)(wateringEndMs - millis()) <= 0){
      watering = false;
      wateringManual = false;
      digitalWrite(PIN_VALVE, LOW);

      lastLine[3] = "";
      lastLine[5] = "";

      int raw = readSoilOncePulsed(false);
      processSoilMeasurement(raw, true);
    }
  }

  if(!watering && !isWetDryEditMode()){
    if(now.hour() >= WINDOW_START_H && now.hour() <= WINDOW_END_H &&
       now.minute() == 0 && now.second() <= 10){

      uint32_t key = makeAutoKey(now);
      if(key != lastAutoKey){
        lastAutoKey = key;

        int raw = readSoilOncePulsed(false);
        processSoilMeasurement(raw, true);

        bool probeOpen = soilIsOpen(moistRaw);

        if(!tempBlock && !probeOpen){
          if(moistPct < TARGET){
            startWatering(false, DUR_MIN);
          }
        }

        lastLine[1] = "";
        lastLine[2] = "";
        lastLine[3] = "";
        lastLine[4] = "";
        lastLine[5] = "";
        lastLine[6] = "";
      }
    }
  }

  static int lastSec = -1;
  int secNow = now.second();

  if(secNow != lastSec || lastLine[0] == ""){
    lastSec = secNow;
    bool hl = rowIsHighlighted(0);
    drawRowTextOnBlack(0, withSelPrefix(buildTimeRow(now), hl), hl ? C_CYAN : seasonTimeColorByMonth(now.month()));
  }
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
